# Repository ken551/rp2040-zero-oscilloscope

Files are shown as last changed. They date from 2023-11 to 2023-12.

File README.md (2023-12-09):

# rp2040-zero-oscilloscope
[picoLabo](https://picolabo.org/)様によるRaspberry Pi Pico オシロスコープと同等のものを、Waveshare社の[RP2040-Zero](https://www.waveshare.com/wiki/RP2040-Zero)を使って実現する、RP2040-Zero-オシロスコープ の回路図です。

> [!CAUTION]
> 本バージョン基板（v1）は回路の**配線ミス**があり、**パターンカット・空中配線**が必須です。
>

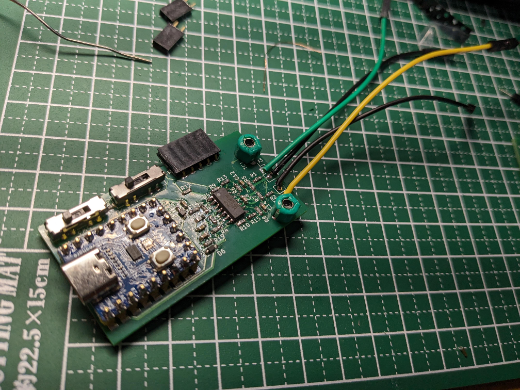
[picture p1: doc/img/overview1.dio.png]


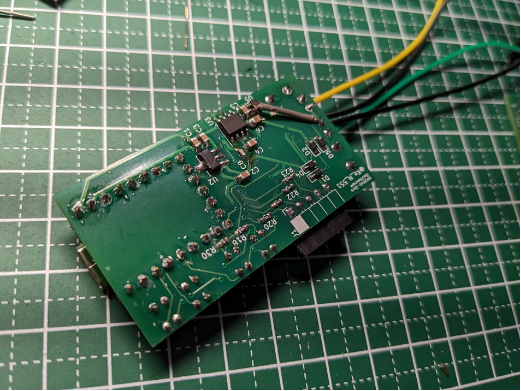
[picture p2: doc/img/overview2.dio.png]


フリスクのケースに（~~無理やり~~）入るサイズです。

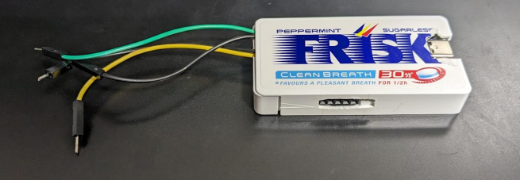
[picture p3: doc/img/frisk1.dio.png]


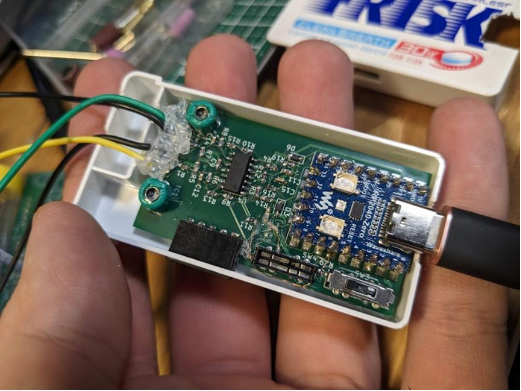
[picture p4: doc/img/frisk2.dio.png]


## **注意**
本バージョンの回路には**間違いがあります。**

## 回路図
[picoLabo](https://picolabo.org/)様の[Raspberry Pi Pico用オシロスコープ基板DIYキット PL2302KIT](https://picolabo.org/pl2302kit/)をベースにしています。小サイズ化のため、ベースの回路図から以下のように変更しています。

* アナログ入力をAC/DC両対応からDCのみに限定
* デジタル入力を8ch→4chに削減
* 信号出力端子を削除

### 使用ライブラリ
* [RP2040-Zero-KiCAD](https://github.com/dj505/RP2040-Zero-KiCAD) (by @dj505)

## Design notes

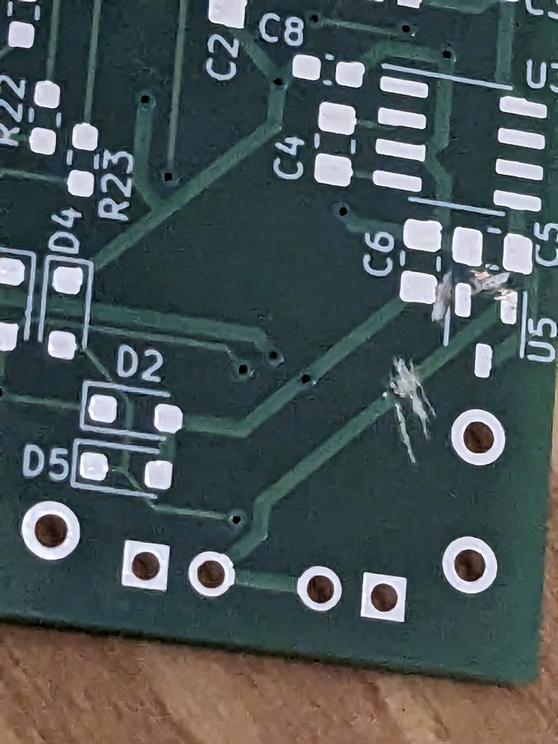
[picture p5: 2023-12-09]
image.png

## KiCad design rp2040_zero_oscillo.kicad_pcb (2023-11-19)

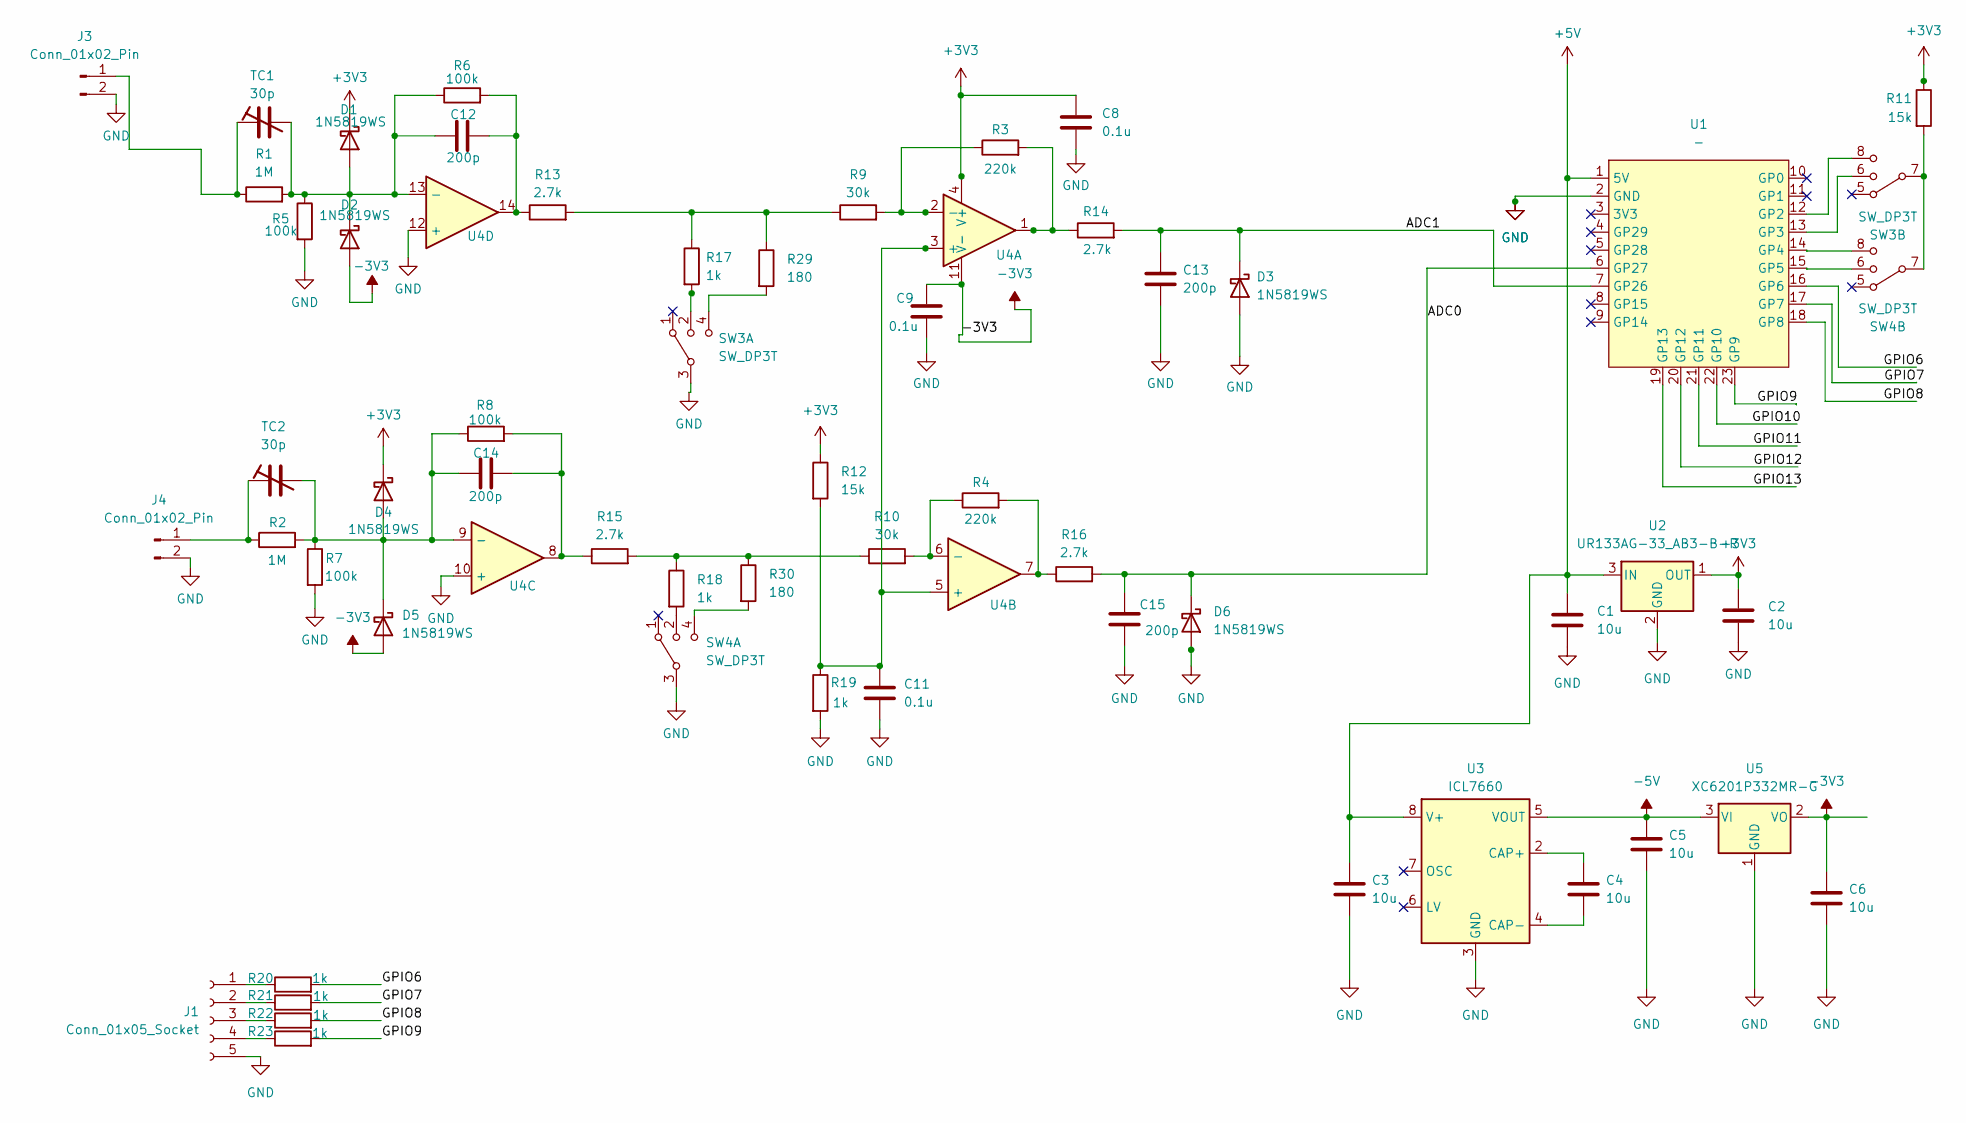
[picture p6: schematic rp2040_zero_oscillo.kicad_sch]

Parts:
C1, C2, C3, C4, C5, C6: 10u; C_0805_2012Metric_Pad1.18x1.45mm_HandSolder
C8, C9, C11: 0.1u; C_0603_1608Metric_Pad1.08x0.95mm_HandSolder
C12, C13, C14, C15: 200p; C_0603_1608Metric_Pad1.08x0.95mm_HandSolder
D1, D2, D3, D4, D5, D6: 1N5819WS; D_SOD-323_HandSoldering
J1: Conn_01x05_Socket; PinSocket_1x05_P2.54mm_Horizontal
J3, J4: Conn_01x02_Pin; PinSocket_1x02_P2.54mm_Vertical
R1, R2: 1M; R_0603_1608Metric_Pad0.98x0.95mm_HandSolder
R3, R4: 220k; R_0603_1608Metric_Pad0.98x0.95mm_HandSolder
R5, R6, R7, R8: 100k; R_0603_1608Metric_Pad0.98x0.95mm_HandSolder
R9, R10: 30k; R_0603_1608Metric_Pad0.98x0.95mm_HandSolder
R11, R12: 15k; R_0603_1608Metric_Pad0.98x0.95mm_HandSolder
R13, R14, R15, R16: 2.7k; R_0603_1608Metric_Pad0.98x0.95mm_HandSolder
R17, R18, R19, R20, R21, R22, R23: 1k; R_0603_1608Metric_Pad0.98x0.95mm_HandSolder
R29, R30: 180; R_0603_1608Metric_Pad0.98x0.95mm_HandSolder
SW3, SW4: SW_DP3T; DP3T_MSS23D18
TC1, TC2: 30p; TMCV01-10P100VB
U1: -; RP2040 Zero
U2: UR133AG-33_AB3-B-R; SOT-89-3_Handsoldering
U3: ICL7660; SOIC-8_3.9x4.9mm_P1.27mm
U4: SOIC-14_3.9x8.7mm_P1.27mm
U5: XC6201P332MR-G; SOT-23-3

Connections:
+3V3: C2.1, C8.1, D1.1 (K), D4.1 (K), R11.1, R12.1, U2.1 (OUT), U4.4 (V+)
+5V: C1.1, C3.1, U1.1 (5V), U2.3 (IN), U3.8 (V+)
-3V3: C6.1, C9.1, D2.2 (A), D5.2 (A), U4.11 (V-), U5.2 (VO)
-5V: C5.1, U3.5 (VOUT), U5.3 (VI)
/ADC0: C15.1, D6.1 (K), R16.2, U1.6 (GP27)
/ADC1: C13.1, D3.1 (K), R14.2, U1.7 (GP26)
/GPIO6: R20.2, U1.16 (GP6)
/GPIO7: R21.2, U1.17 (GP7)
/GPIO8: R22.2, U1.18 (GP8)
/GPIO9: R23.2, U1.23 (GP9)
/GPIO10: U1.22 (GP10)
/GPIO11: U1.21 (GP11)
/GPIO12: U1.20 (GP12)
/GPIO13: U1.19 (GP13)
GND: C1.2, C2.2, C3.2, C5.2, C6.2, C8.2, C9.2, C11.2, C13.2, C15.2, D3.2 (A), D6.2 (A), J1.5, J3.2, J4.2, R5.2, R7.2, R19.2, SW3.3, SW4.3, U1.2 (GND), U2.2 (GND), U3.3 (GND), U4.10 (+), U4.12 (+), U5.1 (GND)
unnamed: C12.2, R6.2, R13.1, U4.14
unnamed: C14.2, R8.2, R15.1, U4.8
unnamed: C12.1, D1.2 (A), D2.1 (K), R1.2, R5.1, R6.1, TC1.2, U4.13 (-)
unnamed: C14.1, D4.2 (A), D5.1 (K), R2.2, R7.1, R8.1, TC2.2, U4.9 (-)
unnamed: J1.1, R20.1
unnamed: J1.2, R21.1
unnamed: J1.3, R22.1
unnamed: J1.4, R23.1
unnamed: J3.1, R1.1, TC1.1
unnamed: J4.1, R2.1, TC2.1
unnamed: R10.1, R15.2, R18.1, R30.1
unnamed: R11.2, SW3.7, SW4.7
unnamed: R9.1, R13.2, R17.1, R29.1
unnamed: R3.2, R14.1, U4.1
unnamed: R4.2, R16.1, U4.7
unnamed: R17.2, SW3.2
unnamed: R18.2, SW4.2
unnamed: R29.2, SW3.4
unnamed: R30.2, SW4.4
unnamed: SW3.8, U1.12 (GP2)
unnamed: SW3.6, U1.13 (GP3)
unnamed: SW4.8, U1.14 (GP4)
unnamed: SW4.6, U1.15 (GP5)
unnamed: C4.1, U3.2 (CAP+)
unnamed: C4.2, U3.4 (CAP-)
unnamed: C11.1, R12.2, R19.1, U4.3 (+), U4.5 (+)
unnamed: R3.1, R9.2, U4.2 (-)
unnamed: R4.1, R10.2, U4.6 (-)

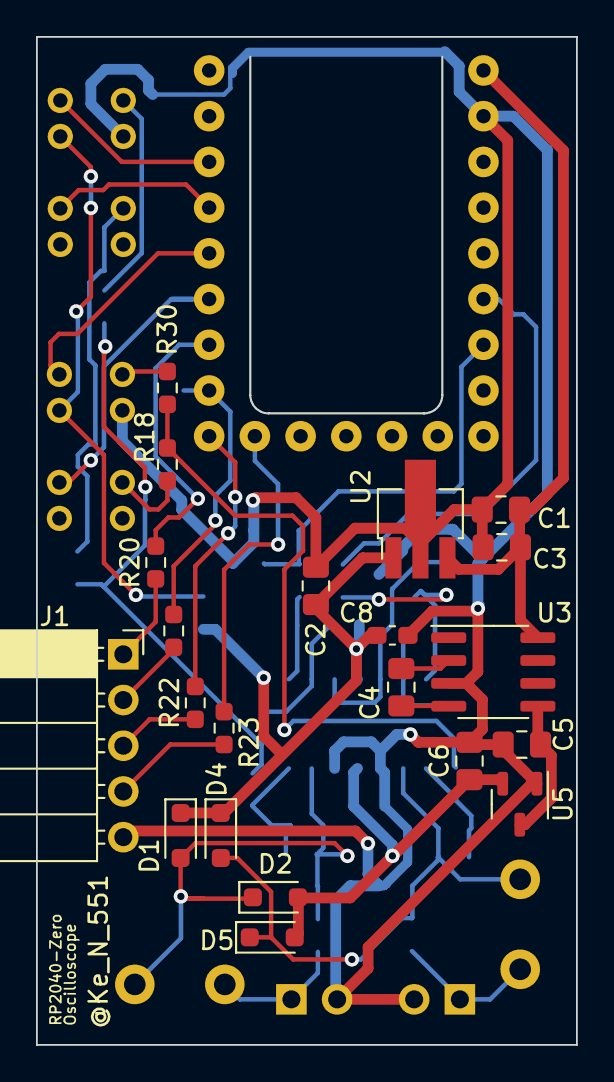
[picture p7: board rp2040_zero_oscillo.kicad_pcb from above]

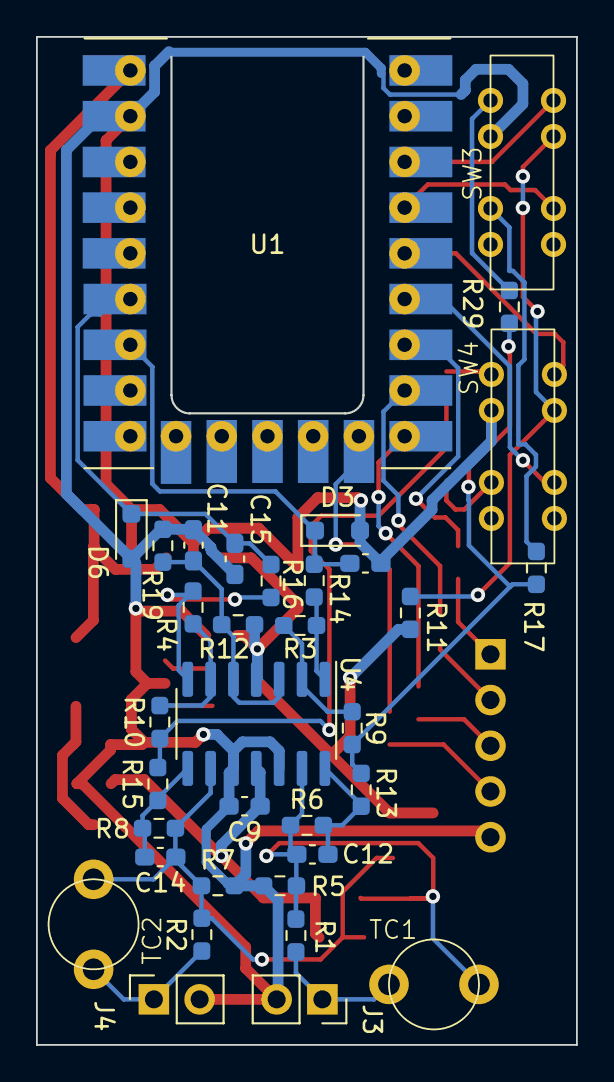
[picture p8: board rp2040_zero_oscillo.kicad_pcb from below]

Board: 2 copper layers, 30.0 x 56.0 mm, 56 parts (35 on the bottom side), 39 nets.

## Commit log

2023-11-19 my first commit
    [rp2040_zero_oscillo.kicad_pcb, rp2040_zero_oscillo.kicad_sch]
2023-11-20 概要を記載@
2023-12-09 配線ミスの注意事項を追記、ドキュメント画像をリサイズ
